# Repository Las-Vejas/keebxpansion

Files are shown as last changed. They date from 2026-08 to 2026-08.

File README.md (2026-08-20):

# keebxpansion
This is an expansion module for the [Hackxpansion Console](https://github.com/hackclub/Hackxpansion). This module features 3 LEDs and one hotswappable MX switch. The module is intended to be used for clicker games like flappy bird or Dino run.
The switch is on GPIO 0 and the LEDs are on GPIOs 1 to 3.

## Gallery

| keebxpansion image 1 | keebxpansion image 2 |
|---|---|
| keebxpansion image 3 | keebxpansion image 4 |

## BOM
|quantity|item |price |link |notes |
|---|---|---|---|---|
|1 |PCBs |$12.00|n/a | |
|1 |1k resistor |$0.00 |n/a |in resistor kit |
|1 |9.1k resistor |$0.00 |n/a |in resistor kit |
|3 |warm white LED |$2.54 |https://fr.aliexpress.com/item/1005010178968219.html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 | |
|3 |33 ohm resistor |$0.00 |n/a |in resistor kit |
|1 |MX switch |$2.76 |https://fr.aliexpress.com/item/1005007253216906.html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 | |
|1 |Hot Swap Socket |$2.18 |https://fr.aliexpress.com/item/1005012011087592.html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{%22order%22%3A%223521%22%2C%22eval%22%3A%221%22%2C%22orig_sl_item_id%22%3A%221005012011087592%22%2C%22orig_item_id%22%3A%221005009794038277%22%2C%22fromPage%22%3A%22search%22}&pdp_npi=6%40dis!USD!4.11!2.06!!!27.47!13.73!%4021038c6f17872428937582643e0d72!12000057272683078!sea!LU!6401819456!X!1!0!n_tag%3A-29919%3Bd%3Ae8030a98%3Bm03_new_user%3A-29895&curPageLogUid=6Fu3TWeCDtcK&utparam-url=scene%3Asearch&#124;query_from%3A&#124;x_object_id%3A1005012011087592&#124;_p_origin_prod%3A1005009794038277|optional |
|1 |resistor kit |$4.70 |https://fr.aliexpress.com/item/1005006202968025.html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 |the resistor kit|
|0 |aliexpress shipping|$12.05|n/a | |
| |TOTAL |$29.26| | |

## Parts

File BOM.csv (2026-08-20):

quantity | item | price | link | notes
1 | PCBs | $12.00 | n/a
1 | 1k resistor | $0.00 | n/a | in resistor kit
1 | 9.1k resistor | $0.00 | n/a | in resistor kit
3 | warm white LED | $2.54 | https://fr.aliexpress.com/item/1005010178968219.html?mp=1
3 | 33 ohm resistor | $0.00 | n/a | in resistor kit
1 | MX switch | $2.76 | https://fr.aliexpress.com/item/1005007253216906.html?mp=1
1 | Hot Swap Socket | $2.18 | https://fr.aliexpress.com/item/1005012011087592.html?curPageLogUid=6Fu3TWeCDtcK&utparam-url=scene%3Asearch|query_from%3A|x_object_id%3A1005012011087592|_p_origin_prod%3A1005009794038277 | optional
1 | resistor kit | $4.70 | https://fr.aliexpress.com/item/1005006202968025.html?curPageLogUid=jc8wnwc6wigE | the resistor kit
0 | aliexpress shipping | $12.05 | n/a
 | TOTAL | $29.26

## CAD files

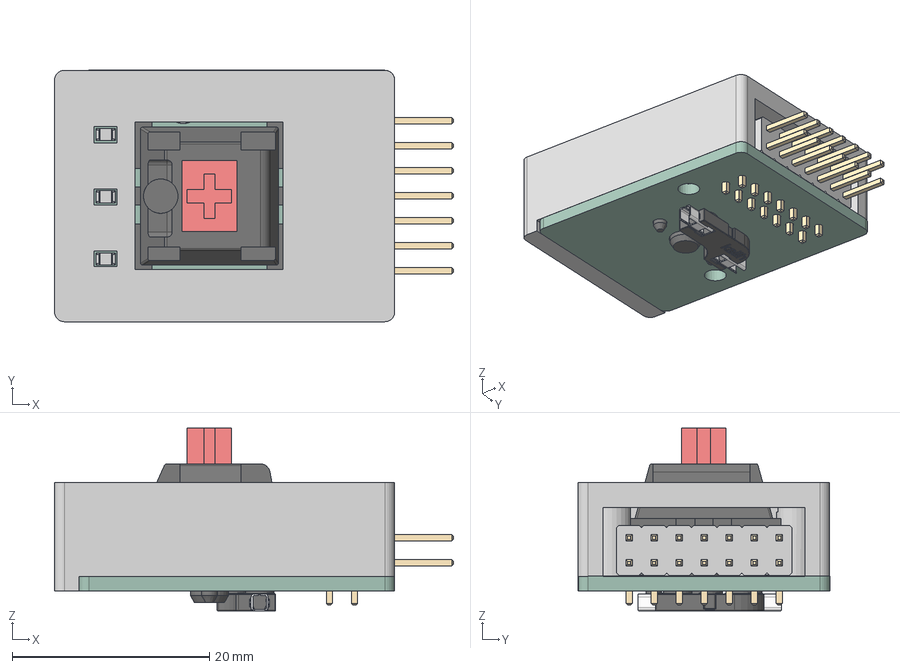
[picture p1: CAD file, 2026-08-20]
3d/Case.step
40.5 x 25.5 x 18.5 mm
R_0402_1005Metric_1 x 5
LED_0805_2012Metric_1 x 3
SW_Hotswap_Kailh_cp
PinHeader_2x07_P254mm_Horizontal
keebxpansion_PCB

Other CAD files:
3d/Case.f3d

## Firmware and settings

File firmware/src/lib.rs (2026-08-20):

#![no_std]

use xpanse_api::{
    bus::allocator::BusAllocator,
    driver::{Driver, DriverError, DriverMeta},
    gpio_bank::{BankPins, GpioBank},
    interfaces::buttons::{A, pin_button},
    interfaces::leds::{Generic, pin_led},
    metadata::{ModuleDetectResistor, ModuleID, ModuleSlot},
    registry::Registry,
};


// Each driver is a struct, that impls the Driver and DriverMeta trait
//
// This struct should stay zero sized
pub struct KeebDriver;

// This trait allows the main firmware to know when should it load this driver,
// on what resistor combination
impl DriverMeta for KeebDriver {
    const ID: ModuleID = ModuleID {
        md0: ModuleDetectResistor::R1K,
        md1: ModuleDetectResistor::R9K1,
    };
}

// This is where the actual business logic happens
impl<G: BankPins> Driver<G> for KeebDriver {
    async fn create(
        // Each driver gets a bank of GPIO pins it can work with, GPIO0 through GPIO10
        gpio_bank: GpioBank<G>,
        // They also get some data about which slot they are in
        slot: ModuleSlot,
        // They also get access to the registry, where they can add peripherals which
        // apps will be able to use. I'll explain this later more in depth
        registry: &mut Registry,
        // They also get access to a bus allocator, since the RP2354 only
        // has 2 I2C, 2 SPI and 2 UART peripherals, not every module can
        // get its own hardware UART for example. I'll also explain this later more in depth
        bus_allocator: &mut BusAllocator,
    ) -> Result<(), DriverError> {

        // Here we add an A button to the registry
        registry.register(
            slot,
            KeebDriver::ID,
            pin_button::<A>(gpio_bank.gpio0.into()),
        );

        // Register LEDs on GPIO1, GPIO2, GPIO3
        registry.register(
            slot,
            KeebDriver::ID,
            pin_led::<Generic>(gpio_bank.gpio1.into(), false),
        );

        registry.register(
            slot,
            KeebDriver::ID,
            pin_led::<Generic>(gpio_bank.gpio2.into(), false),
        );

        registry.register(
            slot,
            KeebDriver::ID,
            pin_led::<Generic>(gpio_bank.gpio3.into(), false),
        );

        // we don't use any busses
        let _ = bus_allocator;

        // You can also spawn new tasks here which run on core 1
        // Apps and resource method calls run on core 0, so you can use both cores
        // Use embassy sync types to communicate between tasks

        Ok(())
    }
}

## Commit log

2026-08-19 added firmware
    [bom.csv]
2026-08-20 pcbs 3d case and readme
    [Case.step, bom.csv, designators.csv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]
2026-08-20 added footprints
2026-08-20 fixed resistor values
